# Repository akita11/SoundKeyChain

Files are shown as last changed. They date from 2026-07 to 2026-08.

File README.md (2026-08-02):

# SoundKeyChain

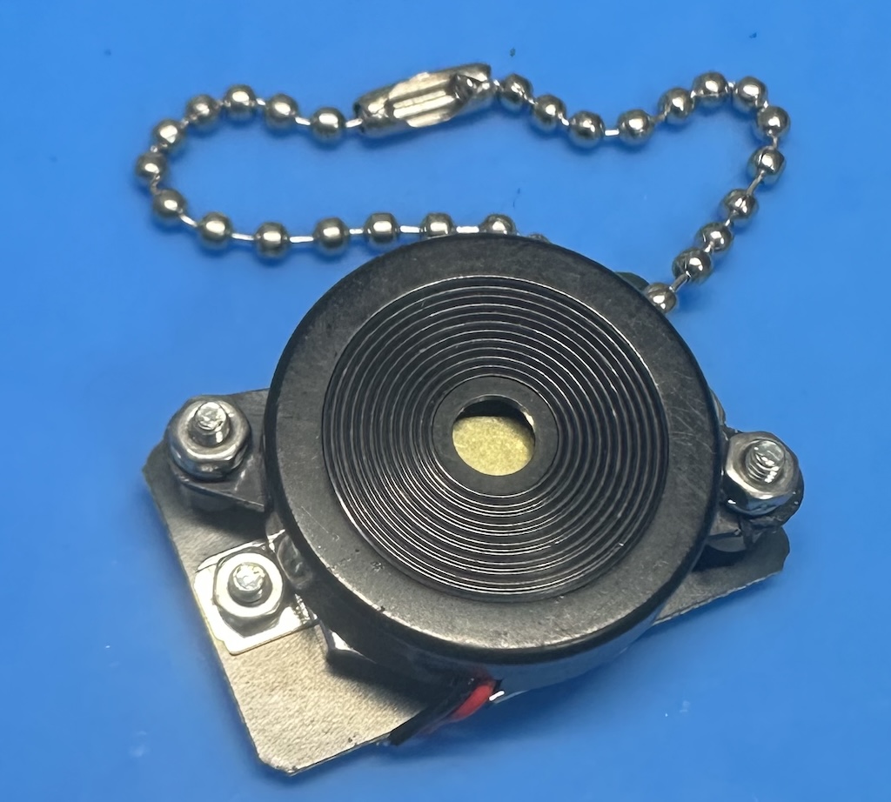
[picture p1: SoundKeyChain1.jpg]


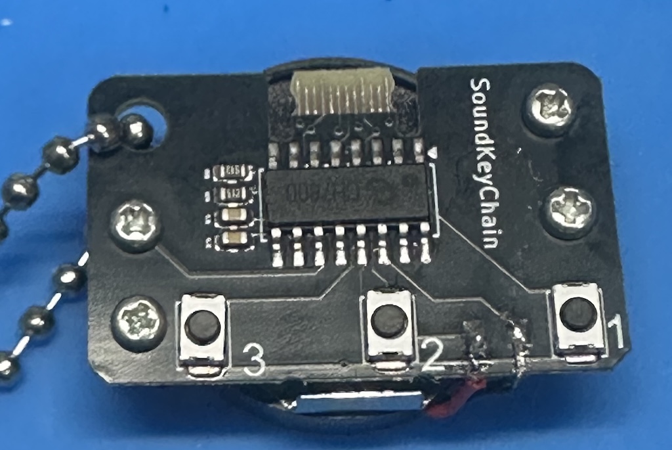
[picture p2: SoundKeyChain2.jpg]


最大3つの音声ファイル（MP3形式）を保存し、ボタンを押して再生します。
お気に入りの音声データをいつも持ち運んで再生できます。。

## 使い方

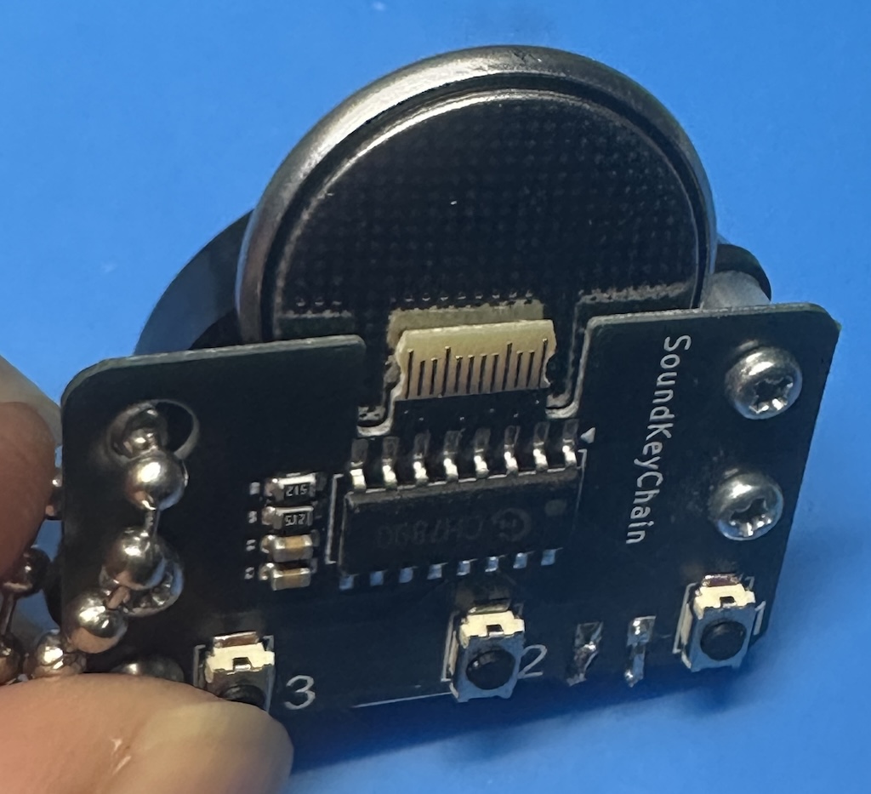
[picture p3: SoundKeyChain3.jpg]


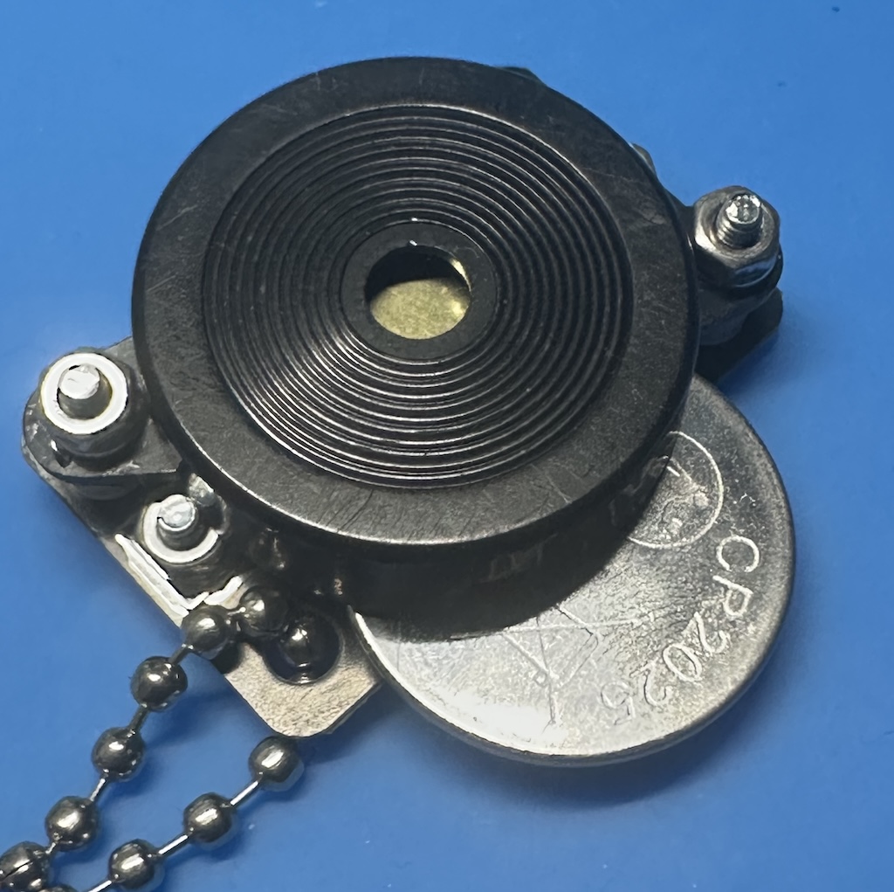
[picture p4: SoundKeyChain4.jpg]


コイン電池(CR2025 or CR2032)を、基板側がマイナス側に向きに差し込みます。

1, 2, 3のボタンを押すと、それぞれ001.mpg, 002.mp3, 003.mp3を再生します。

※音声再生中の消費電流が約10mA程度で、再生終了の約2秒後に低消費電力モード（5uA程度）になります。

[音声再生例](https://github.com/user-attachments/assets/13cc77fd-8777-434c-830f-a518a013cece)

## 音声データの保存

**コイン電池をはずし**、USB Type-CケーブルでPCと接続すると、USBメモリドライブとして認識されます。
用意した音声データ（最大3つ、合計約300KB以下）のファイルをコピーし、とりはずしてください。
ファイル名は、各ボタンに応じて"001.mp3", "002.mp3", "003.mp3"としてください（固定）。

容量は合計で最大300KBのため、必要に応じてビットレートやビット数の調整、モノラル化などの処理を行ってください。
（例えば[Webのmp3データ形式変換サイト](https://online-audio-converter.com/ja/)などを利用できます）

## 音量の変更

PCに接続してUSBメモリとして認識されているドライブの中にあるconfig.txtで機能を設定をできます。設定方法の詳細はconfig.txtに記載されていますが、1行目の2-3文字目（初期設定では"30"）で音量を変更できます（最大30）。

## Author

Junichi Akita (@akita11) / akita@ifdl.jp

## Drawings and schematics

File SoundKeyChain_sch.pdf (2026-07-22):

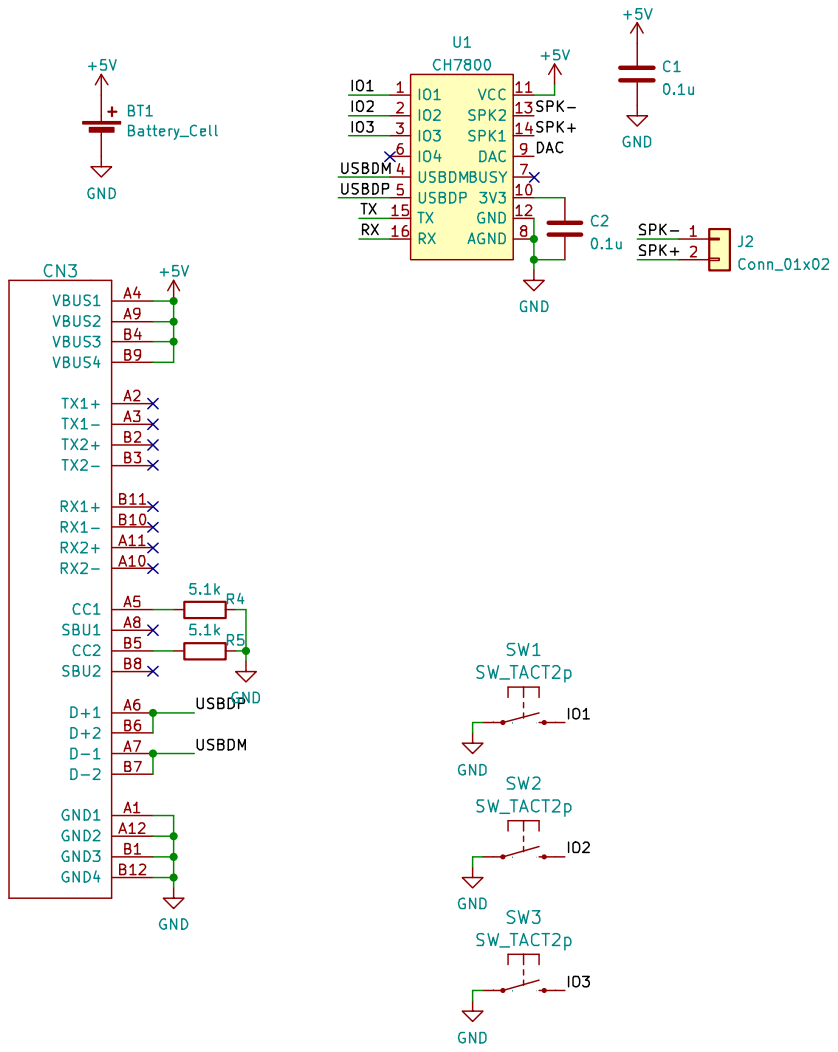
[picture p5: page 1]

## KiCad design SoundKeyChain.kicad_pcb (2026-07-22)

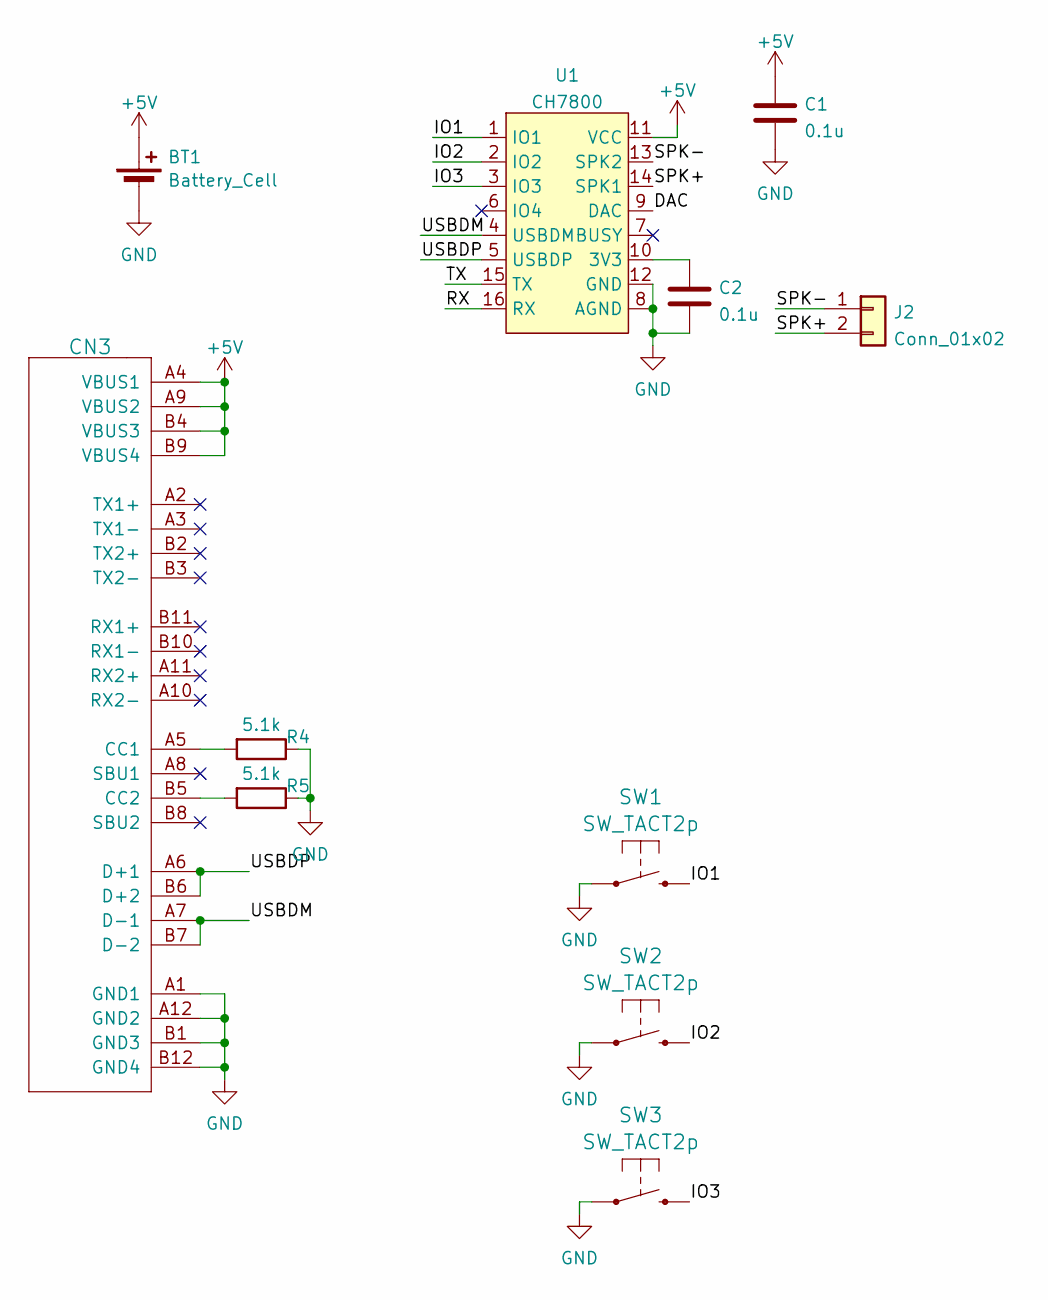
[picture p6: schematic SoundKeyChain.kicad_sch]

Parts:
BT1: Battery_Cell; BAT_CR2032_BC-2001
C1, C2: 0.1u; C_0603_1608Metric
CN3: CON_USB-CPCBPLUG; USB-C_PCBPLUG
J2: Conn_01x02; PinHeader_1x02_P2.54mm_Vertical
R4, R5: 5.1k; R_0603_1608Metric
SW1, SW2, SW3: SW_TACT2p; SW_Push_SPST_NO_Alps_SKRK
U1: CH7800; SOP-16_4.4x10.4mm_P1.27mm

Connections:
+5V: BT1.1 (+), C1.1, CN3.A4 (VBUS1), CN3.A9 (VBUS2), CN3.B4 (VBUS3), CN3.B9 (VBUS4), U1.11 (VCC)
/DAC: U1.9 (DAC)
/IO1: SW1.2, U1.1 (IO1)
/IO2: SW2.2, U1.2 (IO2)
/IO3: SW3.2, U1.3 (IO3)
/RX: U1.16 (RX)
/SPK+: J2.2, U1.14 (SPK1)
/SPK-: J2.1, U1.13 (SPK2)
/TX: U1.15 (TX)
/USBDM: CN3.A7 (D-1), CN3.B7 (D-2), U1.4 (USBDM)
/USBDP: CN3.A6 (D+1), CN3.B6 (D+2), U1.5 (USBDP)
GND: BT1.2 (-), C1.2, C2.2, CN3.A1 (GND1), CN3.A12 (GND2), CN3.B1 (GND3), CN3.B12 (GND4), R4.1, R5.1, SW1.1, SW2.1, SW3.1, U1.8 (AGND), U1.12 (GND)
unnamed: CN3.A5 (CC1), R4.2
unnamed: CN3.B5 (CC2), R5.2
unnamed: C2.1, U1.10 (3V3)

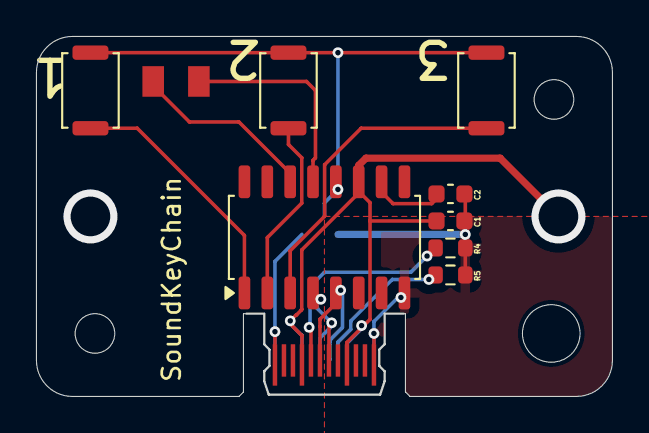
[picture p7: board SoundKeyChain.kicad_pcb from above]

Board: 2 copper layers, 32.0 x 20.0 mm, 11 parts (1 on the bottom side), 12 nets.

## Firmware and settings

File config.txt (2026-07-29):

03001001

※以下はCH7800のデータシートの記載内容の要点を日本語訳したものです（akita11）
音声データ：mp3形式、ファイル名は「001」から「999」（3桁の数値）のみ
容量=約300KB

config.txtの1行目に機能設定を書く。
1文字目: ボタンの動作。0=再生中に中断可、1=再生中に中断不可、2=リピート再生1、3=リピート再生2、4=ON/OFF、5=常時リピート再生
2-3文字目: 音量(00-30)
4文字目: BUSY端子の機能(1=アクティブL、0=アクティブH)
5文字目: 出力(1=PWM(スピーカ)、0=DAC)
6文字目: ボタンの信号極性(0=アクティブL、1=アクティブH)
7文字目: 0=通常動作、1=低電力モード

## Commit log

2026-07-22 initial commit, no photo
    [SoundKeyChain.kicad_pcb, SoundKeyChain.kicad_sch, config.txt]
2026-07-28 Bold the instruction to remove the coin battery
    Emphasized the instruction to remove the coin battery by making it bold.
2026-07-28 Update README with battery and file handling details
    Clarified battery current consumption and file naming instructions.
2026-07-29 add photo
    [config.txt]
2026-07-29 Revise battery setup and power consumption notes
    Updated battery usage instructions and current consumption details.
2026-08-02 README.md を更新
